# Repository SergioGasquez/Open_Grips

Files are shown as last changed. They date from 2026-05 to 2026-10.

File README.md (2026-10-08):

Open Grips – Isolated Frictionless Ergonomic Grip Training for FDP and FDS

## Original Project

The original project uses FreeCad for parametric modeling, and 3D printing for manufacturing. See PDF for full description

## Fitting Prometheus to your hand

See [`prometheus-fit/`](prometheus-fit/README.md): measure your hand from a photo and generate fitted,
print-ready STLs from the original parametric FreeCAD model.

## OpenSCAD models

[`openscad/`](openscad/README.md) rebuilds the Prometheus v43 and Sisyphus v27 STEP files, without the TPU
guard, as parametric OpenSCAD models that export every part for either hand.

## This Fork

The key things I was aiming to improve in this fork were:

### Standard file format

The FreeCAD file format exports were not easy to move between programs for modification. My hope is that by providing a .step file users in the future will be able to open and modify the file to their liking in whatever CAD software they use.

### Ease of printing

The original models were not set up for efficient FDM printing. Through the addition of new angled walls and the adjustment of other areas, the prints are now all sufficiently set up for FDM printing with no supports needed.

- The Sisyphus model has been completely redesigned to take on the style of the Prometheus model in terms of assembly and style, allowing simpler printing *and* assembly
- The pins may now be printed
- The pins may be printed horizontally for strength and reduced failures
- The long, structural pin may also be printed horizontally for strength and reduced failures
- The frame pieces may now be printed sideways, without supports
- The chamfers and fillets on both tools have been generally improved for FDM printing

### Additional guard top piece

I've added a top piece to be printed in TPU as a guard for the tools.

### Documentation

You're reading it! There's more work to be done, but the process of modifying the print files still needs some work.

### Simple file modification for each user

One of the core ideas advertised by a company out there is that each user's hand is a little different and requires minute adjustments to get things just right for each person. In practice, we've found this to be not majorly important (exact measurements and adjustments from person to person do not heavily impact the effectiveness of the training), but for major differences in hand/finger sizes it is definitely still relevant.

In the original models, this modification was done using parametric model variables. I wasn't very familiar with FreeCAD, so in moving over to Fusion360 I dropped the compatibility with these variables. I plan to work on reimplementing them as I'm able. (Unless someone else wants to? :) For now, modification will need to be done by hand.

Until I finish some new tooling for adjusting these files, I'll explain the gist of what we've thought through here:

#### Prometheus

##### Roller Up/Down Offset

The length of the full finger may be used for up/down placement offsets of the rollers. Using the pinky length as "0", you can then calculate the height of the offset of each roller by subtracting the height of the pinky from height of the finger.

So, if your pinky was 60mm:

(Vertical offset of 79mm Ring finger roller pin) = 79mm - 60mm = ~19mm

Vertical offset example

##### Roller Forward/Backward Offset

The length of the PIP joint to the DIP joint ("P->D") may be used for forward/backward offsets of the rollers. Using the pinky length as "0", you can then calculate the offset of each roller by subtracting the length of the pinky P->D from the finger P->D.

So, if your pinky P->D was 18.5mm:

(Horizontal offset of a 27mm Ring finger roller pin) = 27mm - 18.5mm = ~8.5mm

Horizontal offset example

##### Roof Height

The length of the DIP joint to the tip of your finger may be used to calculate the height of the roof of each finger roller to achieve an "ideal" angle to maintain.

(Roof Height) = (DIP to Fingertip) / tan(Desired Angle)

Based on our findings, the desired angles are roughly:

Index: 57°
Middle: 60°
Ring: 60°
Pinky: 55°

So, if your Index finger DIP to Fingertip was 28mm:
(Roof Height) = 28 / tan(57) = ~18.18mm

Roof height example

#### Sisyphus

##### Roller Offset

See each "Roller Offset" area above. Apply the same concepts.

##### Roller Diameter

TBD

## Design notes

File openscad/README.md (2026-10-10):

# OpenSCAD models

Parametric OpenSCAD rebuilds of the fork's printable designs: `prometheus.scad` rebuilds
`../OpenGrips Prometheus v43.step` and `sisyphus.scad` rebuilds `../OpenGrips Sisyphus v27.step`.
Every part (frame, walls, end wall, rollers, pins and post) exports print-ready, for the left or
the right hand, and all of them print in the same material: no metal rods, screws or TPU. The
only extra is the cord through the anchor. Both reproduce their STEP file at the STEP's values
(Prometheus defaults to one measured hand instead, see below), except the STEP files' TPU guard,
which is left out: nothing attaches to it, and the anchor's cord exits are rounded without it.

Requires OpenSCAD 2025 or newer (the Manifold backend; older releases take minutes per part).

## Open in OpenSCAD

Open `prometheus.scad` or `sisyphus.scad`, set the values in the Customizer (Window → Customizer),
pick a `part` and `hand`, render (F6) and export the STL. `part = "assembly"` shows all parts
in place; rendering it takes about a minute.

## Export all parts

```sh
python3 export.py prometheus ../prometheus-fit/examples/right-hand/params.txt --hand right --out my-right-hand
python3 export.py sisyphus --hand left --out sisyphus-left
```

The parameter file is optional and uses the format `../prometheus-fit/measure-hand.html` writes
(`Name = value` lines, `#` comments). The STLs are named like the FreeCAD generator's
(`prometheus_right_frame.stl`, …), so give them their own folder with `--out`.

## Parameters

### Prometheus

Names and meanings match the VarSet of `../Original/OpenGrips_Prometheus.FCStd`; see
`../prometheus-fit/README.md` for how to measure them. The finger defaults (`Height`, `Depth`,
`To_Blocker`) are one measured right hand, recorded at the top of `prometheus.scad` with the v43
values for comparison; the roller and frame sizes are the VarSet's. The frame length follows the middle finger, so its
`Base_M_Height + Base_M_To_Blocker` must be the largest; the model stops with a message if not.
Unlike the FreeCAD model, the ring and middle rails may overlap.

The outer faces of the frame and the end wall carry an engraved `crimpdeq.com` in Inter Bold, as on
the Crimpdeq case; the font is bundled in `fonts/` (SIL Open Font License). The model stops with a
message if the text does not fit between the end wall's post hole and lock.

### Sisyphus

The values of `../Original/OpenGrips_Sisyphus.FCStd`'s VarSet, renamed consistently
(`Base_<F>_height` → `Base_<F>_Height`, `Base_R_diamter` → `Base_R_Diameter`, `I_width` →
`Base_I_Width`, `Base_wall_width` → `Wall_Width`):

| Parameter | Meaning |
|---|---|
| `Base_<F>_Height` | Roller position along the fingers, relative to the pinky |
| `Base_<F>_Blocker` | How far the seat under each roller reaches past its axis (the pinky's stops short of it) |
| `Base_<F>_Diameter`, `Base_<F>_Width` | Roller size; all roller tops are level with the middle roller's |
| `Base_Frame_Height` | Wall length up to the lock slot |

The finger stops and the anchor have no counterpart in the original model and
keep v27's dimensions.

## Printing

The parts export in the orientation `../prometheus-fit/generate.py` uses: frame, walls and
rollers on their pinky-side face with the pole holes vertical, pins on their flat, the post on its
chamfered side. For Prometheus print settings see
`../prometheus-fit/README.md`.

## How faithful

`check_step.py` exports each part at the STEP's own values and compares it with the STEP solid
(run from the repository root; it tessellates the STEP files with FreeCAD's bundled Python):

```sh
uvx --with trimesh --with manifold3d --with scipy --with rtree python openscad/check_step.py
```

Every part is within 0.5% of the STEP volume and within 0.1 mm of its surface at the 95th
percentile, except the Prometheus end wall (0.26 mm) because of its engraving. Known differences:

- Prometheus blocker tips follow the original rule: v43's hand-moved tips sit 0.15–0.38 mm lower.
- Pins are centered in their holes; v43's index pin and v27's ring and index pins are 0.1 mm off.
- Sisyphus: the pinky cradle is approximated by one roller cut.
- Some exports contain a few zero-area triangles where rounded surfaces meet flat ones; slicers
  ignore them.

The comparison is geometric only; fit, strength and comfort still need a test print.

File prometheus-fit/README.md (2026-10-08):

# Fitting Prometheus to your hand

The original FreeCAD model (`../Original/OpenGrips_Prometheus.FCStd`) is still parametric. Two tools drive
it from a photo of your hand and export print-ready STLs. Only Prometheus is covered; Sisyphus is unchanged.

## 1. Measure

Open `measure-hand.html` in Chrome or Safari (single file, nothing to install).

- Photo: palm up, fingers straight and slightly apart, a millimetre ruler beside the fingers raised to
  palm height (e.g. on a book), phone parallel to the table and above the fingers. Use the original
  full-resolution JPEG or PNG, not a screenshot.
- Enter the distance between two ruler marks far apart (e.g. 0 and 10 cm = 100 mm) and click them.
- For each finger, from index to pinky, click the base crease, middle joint (PIP) crease, end joint
  (DIP) crease and fingertip. Scroll to zoom, drag to pan or move a point.
- Copy the text block into `params.txt` in a new folder, e.g. `examples/my-right-hand/params.txt`.

The page sets three values per finger, relative to the pinky:

| Value | Meaning | Computed from |
|---|---|---|
| `Height` | Roller up/down | Fingertip position in the claw grip from `../Original/Open_Grips.pdf` (proximal phalanx vertical, PIP and DIP flexed 55°), including how far each base crease sits along the hand |
| `Depth` | Roller forward/backward | Same claw grip, front-to-back fingertip position |
| `To_Blocker` | Roof height | `DIP→tip / tan(angle)`, with the angles from the [main README](../README.md#roof-height) |

`Height` deliberately differs from the "full finger length minus pinky length" rule in the
[main README](../README.md#roller-updown-offset): that rule ignores that the pinky starts lower on the
hand, which put the rollers 8–14 mm too low on the example hand.

## 2. Generate

With FreeCAD 1.1 installed, from this folder:

```sh
/Applications/FreeCAD.app/Contents/Resources/bin/python generate.py examples/right-hand/params.txt --hand right
```

This writes one STL per part next to `params.txt`, already oriented for printing. The original model is a
left-hand grip; `--hand right` mirrors it. The metal rods of the original are replaced by printed pins
sized like the fork's v43 pins. Parts: frame, ring/middle/index walls, end wall, four rollers, four pins
and the post.

If the ring and middle rollers end up too close, the generator stops and says how much to raise
`Base_M_Height` or lower `Base_R_Height`; split the difference between the two.

The same `params.txt` also drives the OpenSCAD rebuild of the fork's v43 design, without FreeCAD and
without the rail limit: see [`../openscad/`](../openscad/README.md).

`examples/right-hand/` is one person's right hand, as an example.

## 3. Print

All parts in PETG (HF), 0.2 mm layers, 5 walls, 35% cubic infill, textured PEI plate. Enable supports
only for the frame (add a 5 mm brim, it stands 111 mm tall) and the index wall. Pins print lying on
their flat side. `examples/right-hand/prometheus_right_A1.3mf` is a Bambu Lab A1 project with these
settings; rebuild it whenever the STLs change (see `../AGENTS.md`).

Assemble as in `../Original/Open_Grips.pdf` section 3.2: place a roller, insert its pin, slide the next
wall onto the rails, repeat, add the end wall and push the post through the side hole.

The fit has only been checked digitally; adjust the values after a test print.

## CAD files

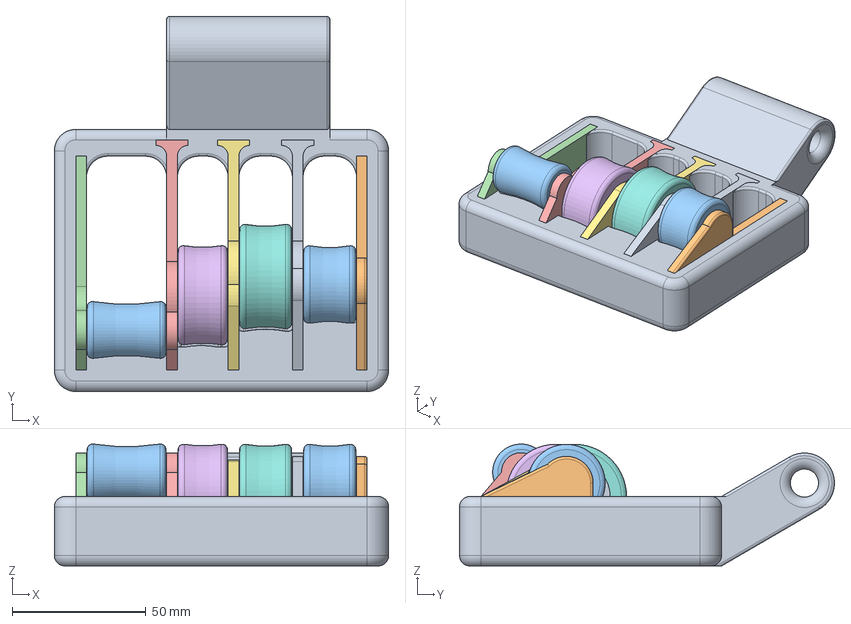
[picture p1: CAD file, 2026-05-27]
docs/templates/OpenGrips_Sisyphus.FCStd
125.0 x 140.2 x 45.6 mm
frame
P_Pole
P_Roller_print
Wall_1_print
Wall_2_print
R_Roller_print
Wall_3_print
M_Roller_print
Wall_4_print
Wall_5_print
I_Roller_print

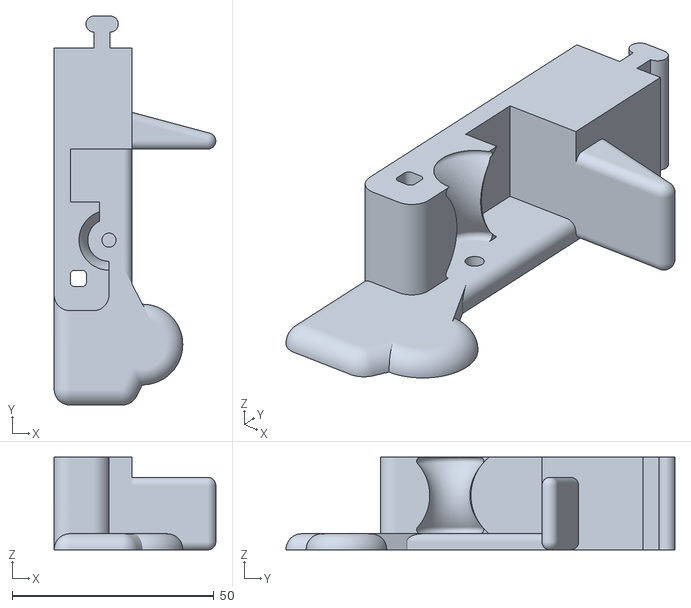
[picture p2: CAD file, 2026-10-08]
prometheus-fit/examples/right-hand/prometheus_right_ring_wall.stl
40.1 x 96.5 x 23.0

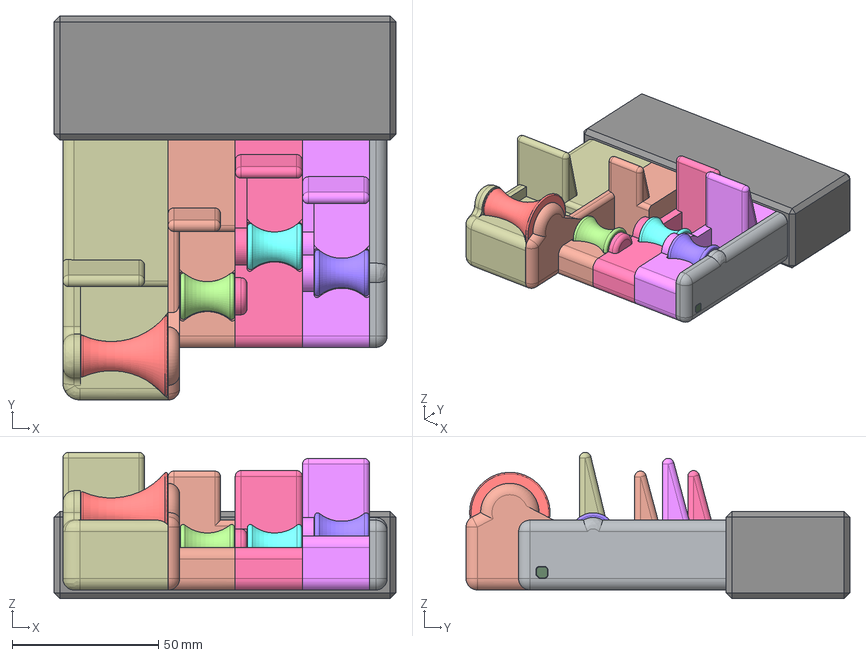
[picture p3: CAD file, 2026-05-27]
prometheus.step
117.0 x 131.4 x 50.1 mm
Frame
Pinky Roller
Pinky Pin
Ring Wall
Ring Roller
Ring Pin
Middle Wall
Middle Roller
Middle Pin
Index Wall
Index Roller
Index Pin
End Wall
Post
Guard

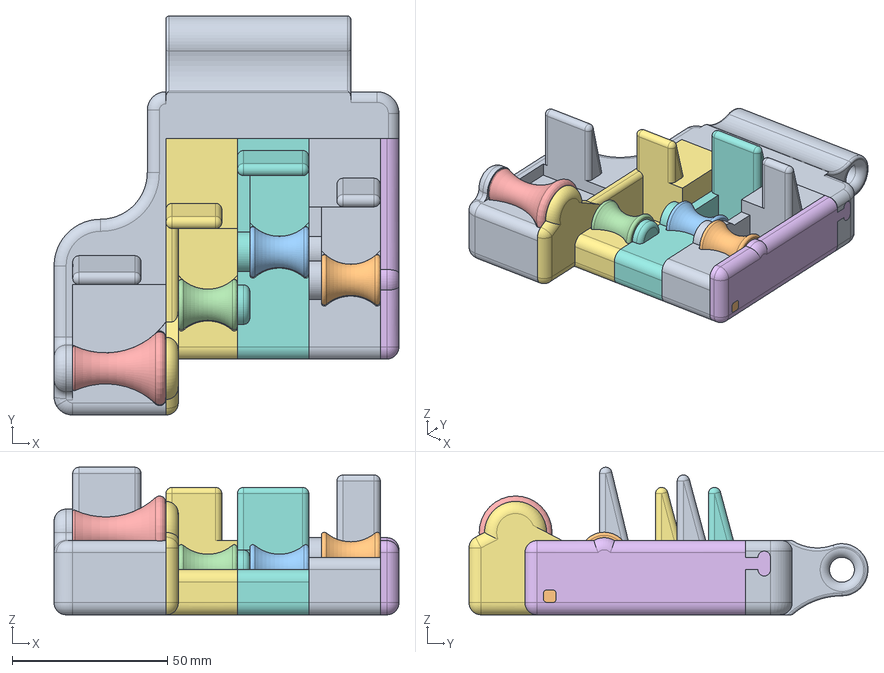
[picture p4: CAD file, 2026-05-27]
docs/templates/OpenGrips_Prometheus.FCStd
111.0 x 128.4 x 47.5 mm
Frame
I_Roller
M_Roller
R_Roller
P_Roller
End_Wall_5
Cut_R_wall
Cut_M_wall
Cut_I_wall
Post

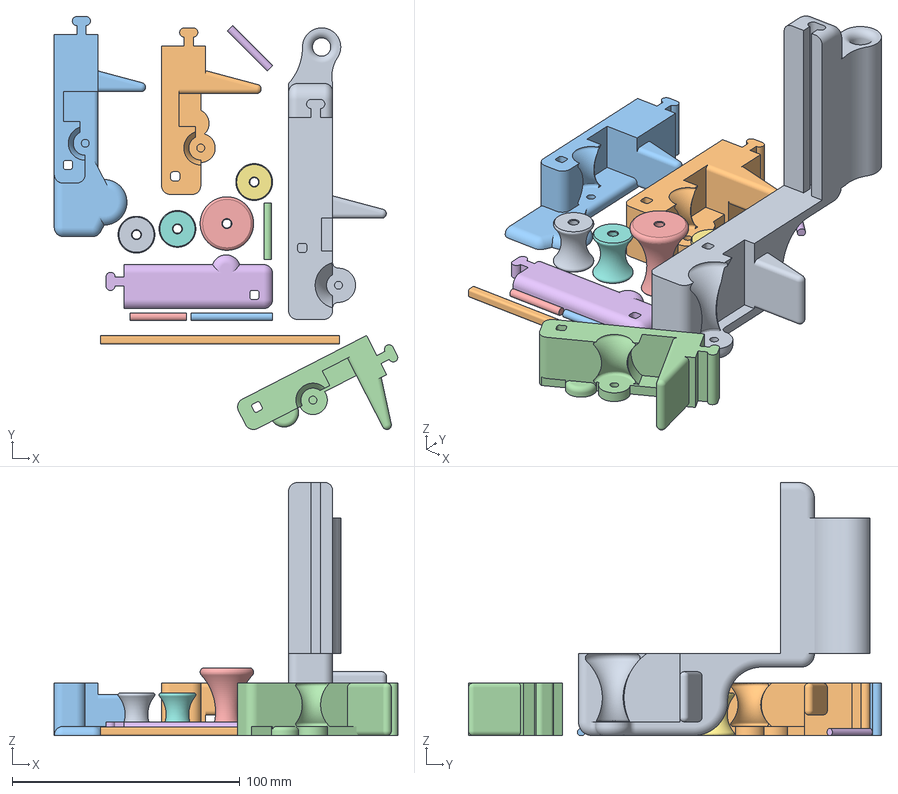
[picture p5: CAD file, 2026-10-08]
prometheus-fit/examples/right-hand/prometheus_right_A1.3mf
150.7 x 181.2 x 111.0 mm
prometheus_right_frame.stl
prometheus_right_index_wall.stl
prometheus_right_ring_wall.stl
prometheus_right_middle_wall.stl
prometheus_right_pinky_roller.stl
prometheus_right_end_wall.stl
prometheus_right_index_roller.stl
prometheus_right_ring_roller.stl
prometheus_right_middle_roller.stl
prometheus_right_post.stl
prometheus_right_pinky_pin.stl
prometheus_right_middle_pin.stl
prometheus_right_index_pin.stl
prometheus_right_ring_pin.stl

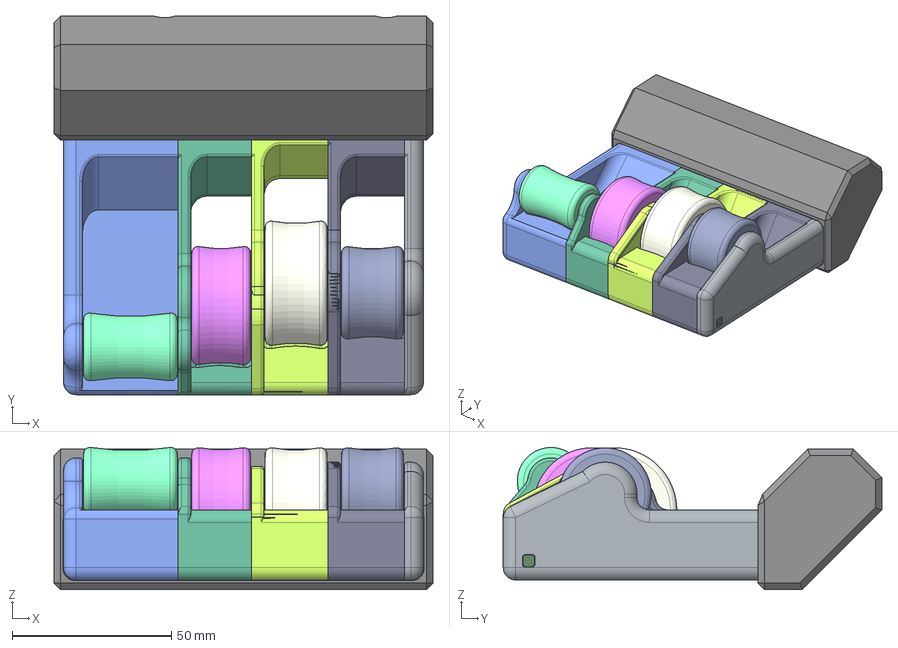
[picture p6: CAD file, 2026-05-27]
sisyphus.step
119.0 x 118.8 x 44.6 mm
Frame
Pinky Roller
Pinky Pin
Ring Wall
Ring Roller
Ring Pin
Middle Wall
Middle Roller
Middle Pin
Index Wall
Index Roller
Index Pin
End Wall
Post
Guard

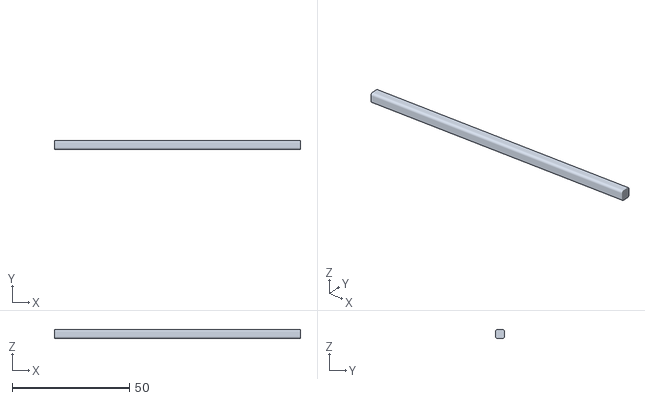
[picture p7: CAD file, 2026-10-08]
prometheus-fit/examples/right-hand/prometheus_right_post.stl
104.8 x 3.80 x 3.80

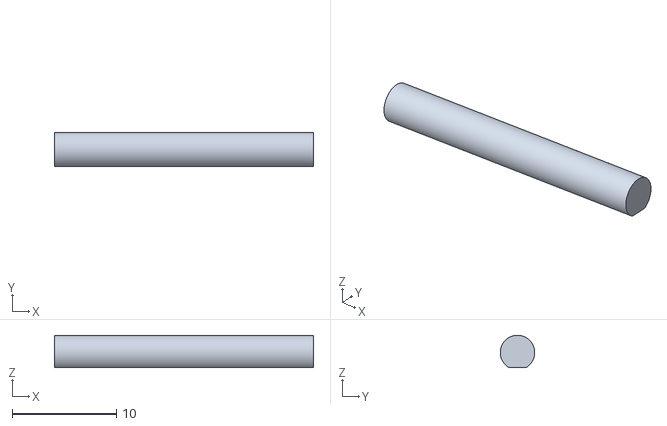
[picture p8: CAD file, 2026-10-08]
prometheus-fit/examples/right-hand/prometheus_right_middle_pin.stl
24.8 x 3.30 x 3.10

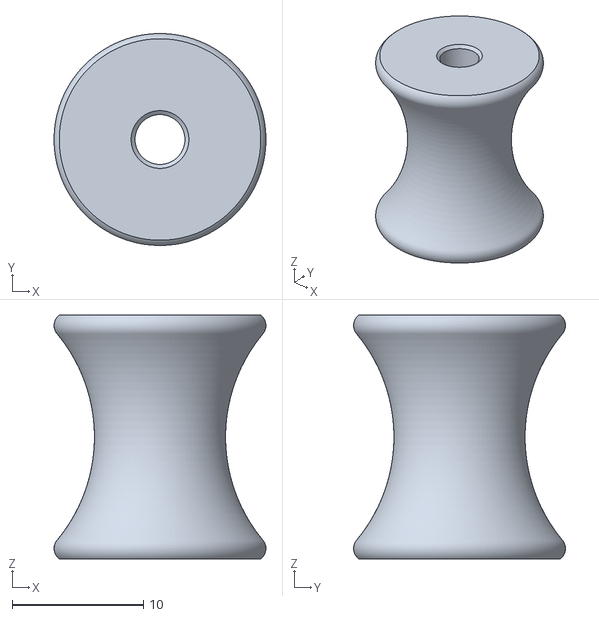
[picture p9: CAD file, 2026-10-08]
prometheus-fit/examples/right-hand/prometheus_right_ring_roller.stl
16.2 x 16.2 x 18.6

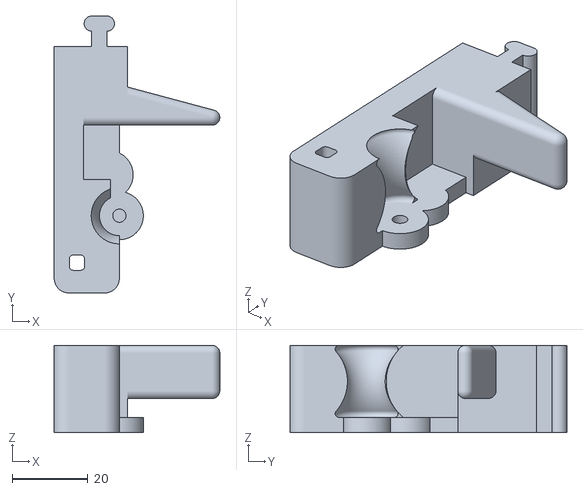
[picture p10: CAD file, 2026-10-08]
prometheus-fit/examples/right-hand/prometheus_right_index_wall.stl
43.7 x 73.1 x 23.0

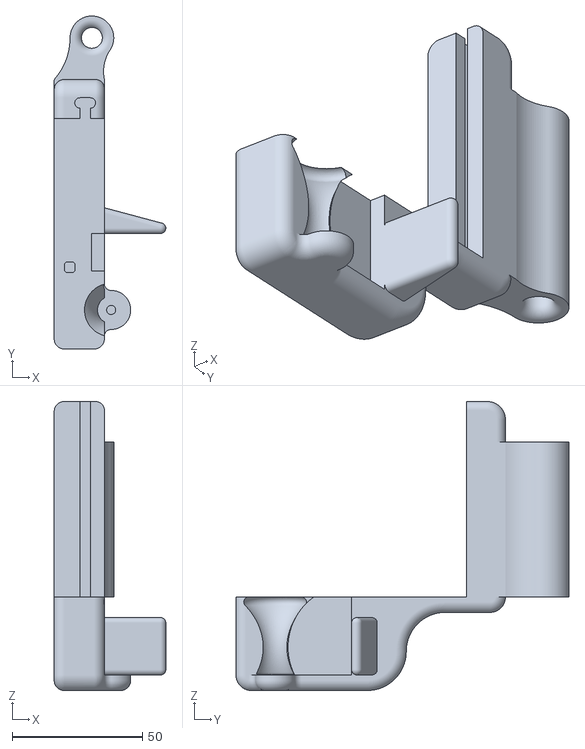
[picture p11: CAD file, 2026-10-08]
prometheus-fit/examples/right-hand/prometheus_right_frame.stl
42.9 x 127.9 x 111.0

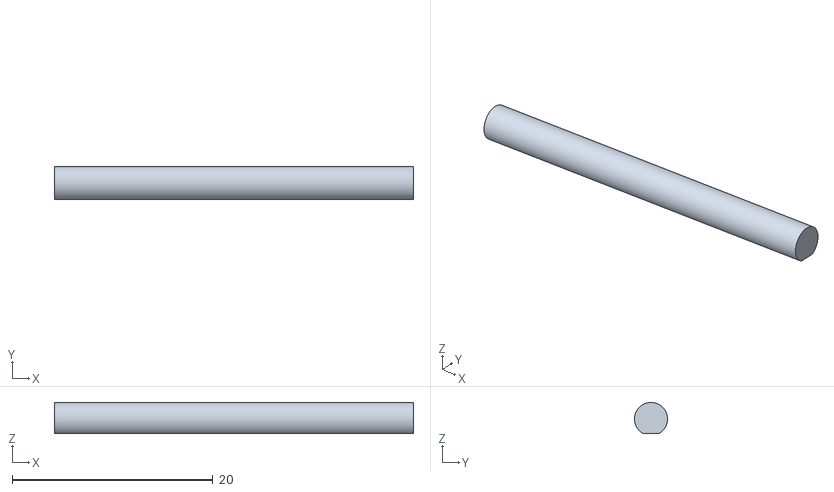
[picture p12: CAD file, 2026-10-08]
prometheus-fit/examples/right-hand/prometheus_right_pinky_pin.stl
35.8 x 3.30 x 3.10

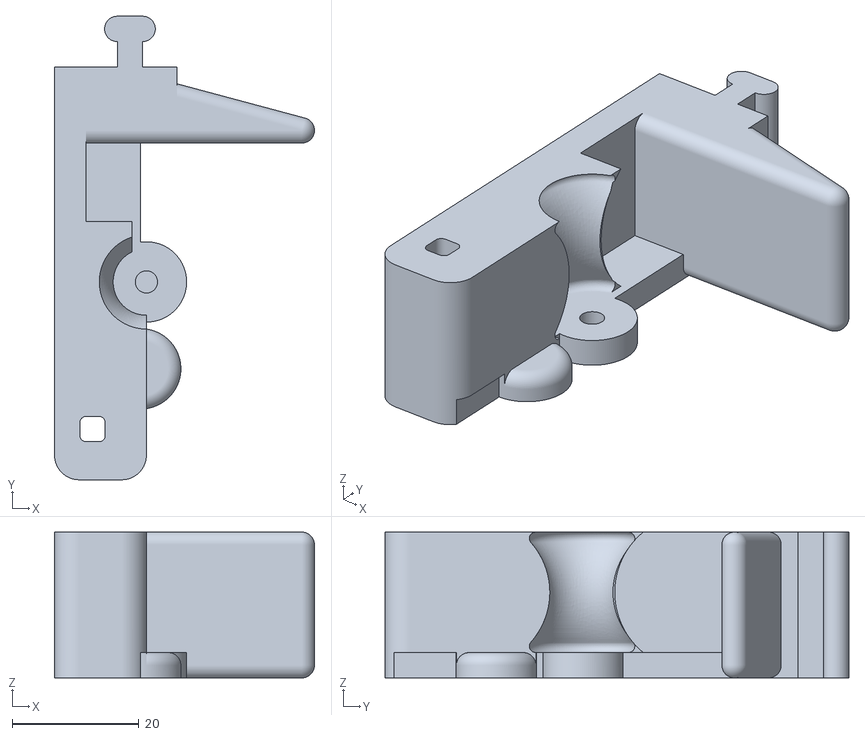
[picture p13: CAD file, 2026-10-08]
prometheus-fit/examples/right-hand/prometheus_right_middle_wall.stl
41.0 x 73.1 x 23.0

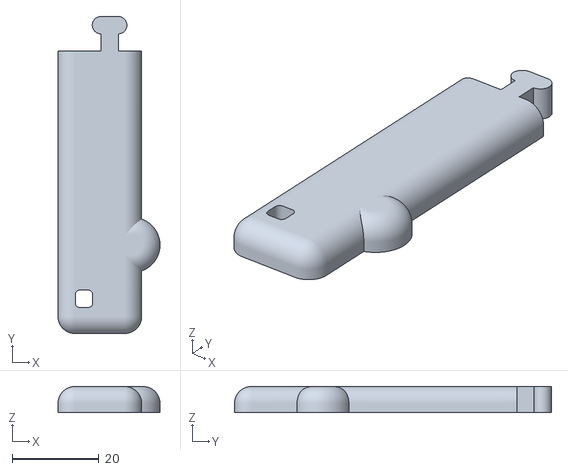
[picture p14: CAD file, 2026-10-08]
prometheus-fit/examples/right-hand/prometheus_right_end_wall.stl
23.5 x 73.1 x 6.00

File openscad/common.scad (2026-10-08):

// Shared building blocks of the OpenGrips models (use <common.scad>).
//
// Model coordinates: X runs across the fingers along the roller axes, Y along the fingers, Z is
// depth; 2D profiles are drawn in (Y, Z) and extruded along X unless noted.

eps = 0.01;

// Extrude a 2D (Y, Z) profile along X.
module along_x(x0, x1) {
  translate([x0, 0, 0]) rotate([90, 0, 90]) linear_extrude(x1 - x0) children();
}

// Extrude a 2D (X, Z) profile along Y.
module along_y(y0, y1) {
  translate([0, y1, 0]) rotate([90, 0, 0]) linear_extrude(y1 - y0) children();
}

// Revolve a 2D (along the axis, radius) profile about the X axis through [x0, y, z].
module about_x_axis(x0, y, z) {
  translate([x0, y, z]) rotate([0, 90, 0]) rotate([0, 0, 90])
    rotate_extrude() rotate([0, 0, 90]) mirror([0, 1, 0]) children();
}

// Round convex corners (r > 0) or concave corners (r < 0) of a 2D shape. Round joins on both
// steps: delta (mitred) joins spike through the shape at tangent cusps.
module round2d(r) {
  offset(r) offset(-r) children();
}

// children() with the convex corners inside the window [p0, p1] rounded by r.
module round_corners_in(r, p0, p1) {
  difference() { children(); translate(p0) square(p1 - p0); }
  intersection() { round2d(r) children(); translate(p0) square(p1 - p0); }
}

// Rectangle from p0 to p1 with its two low-X corners rounded by r.
module front_rounded2d(p0, p1, r) {
  intersection() {
    round2d(r) translate(p0) square([p1[0] - p0[0] + r, p1[1] - p0[1]]);
    translate(p0) square(p1 - p0);
  }
}

// Sphere for rounding: polyhedral spheres fall short of r along the axes, so scale up the facets.
module ball(r) {
  scale(1 / cos(180 / 48)) sphere(r, $fn = 48);
}

// Extrude a (Y, Z) profile along X with the perimeter edges of one end face rounded by r
// (side = 1: the face at x1, side = -1: at x0). children(1), if given, is a larger profile
// whose extra area keeps the edges it covers sharp; it must reach r past those edges.
// The rounded end is the eroded profile, t thick, swept by a ball; the sharp part ends inside
// that core so the two share no faces.
module along_x_rounded(x0, x1, r, side) {
  face = side > 0 ? x1 : x0;
  t = 0.5;
  intersection() {
    along_x(x0, x1) children(0);
    union() {
      if (side > 0) along_x(x0 - 1, x1 - r - t / 2) children($children - 1);
      else along_x(x0 + r + t / 2, x1 + 1) children($children - 1);
      minkowski() {
        along_x(min(face - side * r, face - side * (r + t)), max(face - side * r, face - side * (r + t)))
          offset(-r) children($children - 1);
        ball(r);
      }
    }
  }
}

// Material to remove to round by r the edge along `axis` ("x" or "y") through point `at`, where
// the solid lies toward -sign in the two other axes (sign = [s1, s2]).
module edge_round_cutter(axis, from, to, at, r, sign) {
  module cutter2d() {
    translate(at) scale(sign) difference() {
      translate([-r, -r]) square(r + eps);
      translate([-r, -r]) circle(r);
    }
  }
  if (axis == "x") along_x(from, to) cutter2d();
  else along_y(from, to) cutter2d();
}

function arc_points(c, r, a0, a1, n = 24) =
  [for (k = [0:n]) c + r * [cos(a0 + (a1 - a0) * k / n), sin(a0 + (a1 - a0) * k / n)]];

// Intersection of the circles (c0, r0) and (c1, r1) on the left of the line from c0 to c1.
function circle_intersection(c0, r0, c1, r1) =
  let(d = norm(c1 - c0), u = (c1 - c0) / d, a = (r0 * r0 - r1 * r1 + d * d) / (2 * d))
  c0 + a * u + sqrt(r0 * r0 - a * a) * [-u[1], u[0]];

// Printed pin along X over [x0, x1] at (y, z): a cylinder with a flat on its underside so it
// prints lying down.
module pin(x0, x1, y, z, d, flat) {
  r = d / 2;
  translate([x0, y, z]) difference() {
    rotate([0, 90, 0]) cylinder(r = r, h = x1 - x0);
    translate([-1, -r, -r - 1]) cube([x1 - x0 + 2, 2 * r, 1 + flat]);
  }
}

// Post cross-section (Y, Z) from p (its low corner): a rounded square whose low corner is
// chamfered, which keys the post in its holes.
module post2d(p, size) {
  translate(p) hull() {
    for (q = [[1, size - 1], [size - 1, size - 1], [size - 1, 1]]) translate(q) circle(1);
    polygon([[0, 1], [1, 0], [1, 1]]);
    translate([0, 1]) square([eps, size - 2]);
    translate([1, 0]) square([size - 2, eps]);
  }
}

// Lock tongue / slot cross-section (Y, Z): a bar of thickness w from y0, 2w long, with round
// beads of diameter w at its end that hook the walls into the frame.
module lock2d(y0, z0, w) {
  translate([y0 - eps, z0]) square([2 * w + eps, w]);
  for (z = [z0, z0 + w]) translate([y0 + 1.5 * w, z]) circle(w / 2);
}

// Material removed to round by r the edge where a bore along X (center [y, z], radius rb)
// breaks out of the vertical end plane through p0 (in plan) with outward unit normal n. A ball
// rolls along the edge touching the bore and the plane; between the edge and its path lies the
// cut.
module bore_exit_round(center, rb, p0, n, r) {
  steps = 72;
  d = 0.05; // overshoot into the air so the cut leaves no slivers
  // x where the plane passes through bore radius rho at angle t, offset off along n.
  function x_on_plane(rho, t, off) =
    let(y = center[0] + rho * cos(t)) (n * p0 + off - n[1] * y) / n[0];
  function ring(rho, t) = center + rho * [cos(t), sin(t)];
  function corner(t) = let(
    e = concat([x_on_plane(rb, t, 0)], ring(rb, t)),
    c = concat([x_on_plane(rb + r, t, -r)], ring(rb + r, t)),
    f1 = concat([c[0]], ring(rb - d, t)),
    f2 = c + (r + d) * [n[0], n[1], 0],
    out = (e - c) / norm(e - c))
    [e + d * out, f1, f2, c];
  // Neighbouring pieces overlap slightly so they share no faces.
  for (k = [0:steps - 1]) {
    a = corner(360 * (k - 0.1) / steps);
    b = corner(360 * (k + 1.1) / steps);
    // The ball is a touch larger so its path crosses the bore and plane instead of touching
    // them, which booleans cannot resolve cleanly.
    difference() {
      hull() for (q = [a[0], a[1], a[2], b[0], b[1], b[2]]) translate(q) cube(0.01, center = true);
      hull() for (q = [a[3], b[3]]) translate(q) ball(r + 0.02);
    }
  }
}

// Mirror for a right-hand grip; the models are left-hand grips.
module hand_mirror(hand) {
  assert(hand == "left" || hand == "right", str("hand must be left or right, got ", hand));
  if (hand == "right") mirror([1, 0, 0]) children();
  else children();
}

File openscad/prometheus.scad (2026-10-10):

// OpenGrips Prometheus: parametric rebuild of the fork's "OpenGrips Prometheus v43.step".
//
// Coordinates follow the original FreeCAD model, a left-hand grip: X runs across the fingers
// along the roller axes (pinky at low X), Y along the fingers, Z is depth (frame bottom at 0).
// Parameter names and meanings match the VarSet of ../Original/OpenGrips_Prometheus.FCStd, so the
// output of ../prometheus-fit/measure-hand.html applies unchanged.

use <common.scad>
use <fonts/Inter-Bold.ttf>

/* [Output] */
part = "assembly"; // [assembly, frame, pinky_roller, ring_roller, middle_roller, index_roller, ring_wall, middle_wall, index_wall, end_wall, pinky_pin, ring_pin, middle_pin, index_pin, post]
// The model is a left-hand grip; right mirrors every part.
hand = "left"; // [left, right]

/* [Fingers, relative to the pinky (mm)] */
// Defaults: one measured right hand, measure-hand.html on PXL_20261008_143506195.jpg (ruler 100 mm,
// 12.6 px/mm). v43 itself: Height 23/32/15/0, Depth 8/12/12/0, To_Blocker 14.2/13.9/12.7/8.8
// (index/middle/ring/pinky) and Base_Frame_Height 104.
// Roller up/down (fingertip position along the fingers)
Base_I_Height = 23.5;
Base_M_Height = 32.1;
Base_R_Height = 22.0;
Base_P_Height = 0;
// Roller forward/backward
Base_I_Depth = 4.2;
Base_M_Depth = 6.7;
Base_R_Depth = 8.4;
Base_P_Depth = 0;
// Roof height: roller top to blocker
Base_I_To_Blocker = 13.8;
Base_M_To_Blocker = 12.0;
Base_R_To_Blocker = 13.2;
Base_P_To_Blocker = 13.9;

/* [Rollers (mm)] */
Base_I_Diameter = 19;
Base_M_Diameter = 19;
Base_R_Diameter = 19;
Base_P_Diameter = 30;
Base_I_Width = 19;
Base_M_Width = 19;
Base_R_Width = 19;
Base_P_Width = 30;

/* [Frame (mm)] */
Wall_Width = 4;
Base_Ext_Wall_Width = 6;
Base_Blocker_Height = 30;
// The original metal pole; still sets the frame thickness and rail details.
Base_Pole_Diameter = 2.6;

/* [Printed pins (mm)] */
pin_diameter = 3.3;
pin_flat = 0.2; // flat along the pin so it prints lying down
pin_end_clearance = 0.1; // to each blind hole bottom
pin_hole_diameter = 3.5;
roller_bore_diameter = 3.8;
roller_bore_chamfer = 0.5;
roller_side_clearance = 0.2; // to each wall
post_clearance = 0.15; // per side

/* [Hidden] */
in_place = false; // export a part in assembly coordinates (checks against the STEP)
$fa = 3;
$fs = 0.3;
eps = 0.01;

// Fingers in X order from the pinky side.
P = 0; R = 1; M = 2; I = 3;
FINGERS = ["pinky", "ring", "middle", "index"];
HEIGHT = [Base_P_Height, Base_R_Height, Base_M_Height, Base_I_Height];
DEPTH = [Base_P_Depth, Base_R_Depth, Base_M_Depth, Base_I_Depth];
TO_BLOCKER = [Base_P_To_Blocker, Base_R_To_Blocker, Base_M_To_Blocker, Base_I_To_Blocker];
DIAMETER = [Base_P_Diameter, Base_R_Diameter, Base_M_Diameter, Base_I_Diameter];
WIDTH = [Base_P_Width, Base_R_Width, Base_M_Width, Base_I_Width];

E = Base_Ext_Wall_Width;
W = Wall_Width;
POLE = Base_Pole_Diameter;
Base_Frame_Depth = Base_M_Depth + Base_M_Diameter / 2 + 5;
Base_Frame_Height = 2 * E + Base_P_Diameter + Base_M_Height + Base_M_To_Blocker + 15;
Base_Frame_Width = 3 * W + WIDTH[P] + WIDTH[R] + WIDTH[M] + WIDTH[I] + 2 * E;
FD = Base_Frame_Depth;
FW = Base_Frame_Width;
T = FD - POLE; // thickness (Z) of the frame plate and the walls
FRAME_TOP = E + Base_Frame_Height; // Y where the anchor starts

ROLLER_WAIST = 5; // smallest roller radius
POLE_HOLE_DEPTH = 3;
EDGE_R = 3.9; // outer edge rounds (Wall_Width - 0.1 in the FreeCAD model)
BLOCKER_R = 2; // blocker tip and edge rounds
FLOOR_ABOVE_ROLLER = 1; // the floor in front of each roller sits this far above its bottom
CRADLE_SCALE = 1.05; // radial clearance of the cradle under each roller

// Rollers, walls and blockers (Y, Z in assembly coordinates).
function sum(v, n) = n <= 0 ? 0 : v[n - 1] + sum(v, n - 1);
function roller_x(f) = E + sum(WIDTH, f) + f * W;
function wall_x(f) = roller_x(f) - W; // the wall plate on the pinky side of roller f
END_WALL_X = roller_x(I) + WIDTH[I];
function axis_y(f) = E + DIAMETER[P] + HEIGHT[f] - DIAMETER[f] / 2;
function axis_z(f) = FD - DEPTH[f];
function axis(f) = [axis_y(f), axis_z(f)];
function blocker_y(f) = E + DIAMETER[P] + HEIGHT[f] + TO_BLOCKER[f];
// Roller end radii: the pinky roller is a cone-like spool, the others are symmetric.
function roller_end_radii(f) = f == P ? [DIAMETER[P] / 4, DIAMETER[P] / 2] : [DIAMETER[f] / 2, DIAMETER[f] / 2];

// Concave roller profile: a circle through both end radii with ROLLER_WAIST as its lowest point.
// Returns [center along the roller, radius] for a roller of width w.
function roller_arc(w, r0, r1) =
  let(a = r0 - ROLLER_WAIST, b = r1 - ROLLER_WAIST)
  a == b ? [w / 2, (w * w / 4 + a * a) / (2 * a)]
  : let(A = 1 - b / a, c = (2 * w - sqrt(4 * w * w - 4 * A * (w * w + b * b - a * b))) / (2 * A))
    [c, (c * c + a * a) / (2 * a)];

WALL_Y0 = E + DIAMETER[P] + HEIGHT[R] - DIAMETER[R] - 2 * W; // front of the ring, middle, index and end walls
LOCK_Y = Base_Frame_Height - E - 15 + 3 * W; // crossbar front, lock slot start
LOCK_Z = FD - 3 * W;
POST_Y = WALL_Y0 + E;
POST_Z = W;
POST_SIZE = 4;

// Anchor: tube along X behind the crossbar that a cord pulls on.
ANCHOR_Y = FRAME_TOP + 16;
ANCHOR_Z = FD - Base_M_Depth;
ANCHOR_BORE_R = 4;
ANCHOR_R = ANCHOR_BORE_R + 4.4;
ANCHOR_X0 = E + WIDTH[P]; // its 45 degree ends pass through these X at the tube top
ANCHOR_X1 = roller_x(I) + WIDTH[I] / 2;
CORD_EXIT_R = 3; // round of the bore where it breaks out of the anchor ends

// Engraved on the outer faces of the frame and the end wall, as on the back of the Crimpdeq case.
// Centered between the end wall's post hole and lock, at the same Y on the frame.
BRAND_TEXT = "crimpdeq.com";
BRAND_FONT = "Inter:style=Bold";
BRAND_SIZE = 4.5;
BRAND_DEPTH = 0.8;
BRAND_Y = (POST_Y + POST_SIZE + LOCK_Y) / 2;
BRAND_EXTENT = textmetrics(BRAND_TEXT, size = BRAND_SIZE, font = BRAND_FONT).size; // [along Y, Z]

for (f = [P:I])
  assert(blocker_y(f) + 2 * BLOCKER_R < LOCK_Y,
         str(FINGERS[f], " blocker (Y ", blocker_y(f), ") reaches the crossbar (Y ", LOCK_Y,
             "): the middle finger must have the largest Height + To_Blocker"));
assert(BRAND_EXTENT[0] + 2 < LOCK_Y - POST_Y - POST_SIZE,
       str("the end wall (", LOCK_Y - POST_Y - POST_SIZE, " mm between post hole and lock) is too short for ",
           BRAND_TEXT));
assert(BRAND_Y - BRAND_EXTENT[0] / 2 > axis_y(P) + DIAMETER[P] / 4 + POLE,
       str(BRAND_TEXT, " reaches the pinky pole wall on the frame"));
assert(BRAND_EXTENT[1] + 1 < T - 2 * EDGE_R,
       str("the frame (", T, " mm thick) is too thin for ", BRAND_TEXT));

// ---------------------------------------------------------------------------------------------
// Rollers, pins, post

// Half profile (along the axis, radius) of roller f over [u0, u1], ends rounded by [rf0, rf1].
module roller_half_profile(f, u0, u1, rf) {
  w = WIDTH[f];
  arc = roller_arc(w, roller_end_radii(f)[0], roller_end_radii(f)[1]);
  rmax = max(roller_end_radii(f)) + 1;
  // Mirror across the axis so rounding leaves the axis side alone, then keep the upper half.
  intersection() {
    translate([u0 - 1, 0]) square([u1 - u0 + 2, rmax + 1]);
    union() {
      for (k = [0, 1]) intersection() {
        round2d(rf[k]) roller_body2d();
        translate([k == 0 ? u0 - 1 : (u0 + u1) / 2, -rmax - 1]) square([(u1 - u0) / 2 + 1, 2 * rmax + 2]);
      }
    }
  }
  module roller_body2d() {
    difference() {
      translate([u0, -rmax]) square([u1 - u0, 2 * rmax]);
      for (s = [1, -1]) translate([arc[0], s * (ROLLER_WAIST + arc[1])]) circle(arc[1]);
    }
  }
}

// Solid of revolution about the roller f axis from a (along the axis, radius) profile at local u.
module about_roller_axis(f) {
  about_x_axis(roller_x(f), axis_y(f), axis_z(f)) children();
}

// The printed roller: trimmed for side clearance, ends rounded, chamfered bore for the pin.
module roller(f) {
  w = WIDTH[f];
  rf = f == P ? 0.5 : 1;
  c = roller_side_clearance;
  difference() {
    about_roller_axis(f) roller_half_profile(f, c, w - c, [rf, rf]);
    about_roller_axis(f) polygon([
      [c - eps, 0], [c - eps, roller_bore_diameter / 2 + roller_bore_chamfer + eps],
      [c + roller_bore_chamfer, roller_bore_diameter / 2], [w - c - roller_bore_chamfer, roller_bore_diameter / 2],
      [w - c + eps, roller_bore_diameter / 2 + roller_bore_chamfer + eps], [w - c + eps, 0]]);
  }
}

// Space cut under roller f: the original roller (no side clearance, its own end rounds) with
// CRADLE_SCALE radial clearance, never wider than its largest end. It reaches eps past the
// walls on both sides so its ends never coincide with their faces.
module cradle(f) {
  w = WIDTH[f];
  rf = f == P ? [0.5, 0] : [1, 1];
  about_roller_axis(f) translate([w / 2, 0]) scale([(w + 2 * eps) / w, 1]) translate([-w / 2, 0]) intersection() {
    scale([1, CRADLE_SCALE]) roller_half_profile(f, 0, w, rf);
    square([w, max(roller_end_radii(f))]);
  }
}
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

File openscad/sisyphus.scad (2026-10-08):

// OpenGrips Sisyphus: parametric rebuild of the fork's "OpenGrips Sisyphus v27.step".
//
// Coordinates: a left-hand grip, X across the fingers along the roller axes (pinky at low X),
// Y along the fingers, Z depth; the frame's front bottom corner is the origin (the STEP is
// offset by [5.965, 8.069, 4.13]). Parameters follow the VarSet of
// ../Original/OpenGrips_Sisyphus.FCStd under consistent names (there: Base_<F>_height,
// Base_<F>_blocker, Base_<F>_diameter, Base_R_diamter, I_width, Base_wall_width).

use <common.scad>

/* [Output] */
part = "assembly"; // [assembly, frame, pinky_roller, ring_roller, middle_roller, index_roller, ring_wall, middle_wall, index_wall, end_wall, pinky_pin, ring_pin, middle_pin, index_pin, post]
// The model is a left-hand grip; right mirrors every part.
hand = "left"; // [left, right]

/* [Fingers, relative to the pinky (mm)] */
// Roller position along the fingers
Base_I_Height = 21;
Base_M_Height = 29;
Base_R_Height = 21;
Base_P_Height = 0;
// Seat under each roller: how far it reaches past the roller axis (pinky: short of it)
Base_I_Blocker = 4;
Base_M_Blocker = 9;
Base_R_Blocker = 10;
Base_P_Blocker = 1;

/* [Rollers (mm)] */
Base_I_Diameter = 30;
Base_M_Diameter = 40;
Base_R_Diameter = 38;
Base_P_Diameter = 22;
Base_I_Width = 20;
Base_M_Width = 20;
Base_R_Width = 19;
Base_P_Width = 30;

/* [Frame (mm)] */
Wall_Width = 4;
Base_Ext_Wall_Width = 6;
// Length of the walls up to the lock slot
Base_Frame_Height = 80;

/* [Printed pins (mm)] */
pin_diameter = 3.3;
pin_flat = 0.2; // flat along the pin so it prints lying down
pin_end_clearance = 0.1; // to each blind hole bottom
pin_hole_diameter = 3.5;
roller_bore_diameter = 3.8;
roller_side_clearance = 0.25; // to each wall
post_clearance = 0.15; // per side

/* [Hidden] */
in_place = false; // export a part in assembly coordinates (checks against the STEP)
$fa = 3;
$fs = 0.3;
eps = 0.01;

// Fingers in X order from the pinky side.
P = 0; R = 1; M = 2; I = 3;
FINGERS = ["pinky", "ring", "middle", "index"];
HEIGHT = [Base_P_Height, Base_R_Height, Base_M_Height, Base_I_Height];
BLOCKER = [Base_P_Blocker, Base_R_Blocker, Base_M_Blocker, Base_I_Blocker];
DIAMETER = [Base_P_Diameter, Base_R_Diameter, Base_M_Diameter, Base_I_Diameter];
WIDTH = [Base_P_Width, Base_R_Width, Base_M_Width, Base_I_Width];

E = Base_Ext_Wall_Width;
W = Wall_Width;
FW = 3 * W + WIDTH[P] + WIDTH[R] + WIDTH[M] + WIDTH[I] + 2 * E; // frame width
WH = Base_M_Diameter / 2 + W / 2; // wall and frame height (Z)

EDGE_R = 3.9; // outer edge rounds
TOP_EDGE_R = 1; // rounds along the wall plate tops
ROLLER_ARC_R = [80, 40, 40, 40]; // concave roller profile radius
ROLLER_END_R = 2;
CRADLE_SCALE = 1.05; // the cradles are cut by the original rollers scaled up by this
// v27 cuts each cradle with roller tools at these offsets from the roller slot (twice, leftovers
// of the original model; the pinky's single cut is fitted to v27).
CRADLE_TOOL_OFFSETS = [[-1], [0, -1.75], [0, -0.75], [0, 0.25]];

// Rollers (Y, Z in assembly coordinates). All roller tops are level with the middle roller's.
function sum(v, n) = n <= 0 ? 0 : v[n - 1] + sum(v, n - 1);
function roller_x(f) = E + sum(WIDTH, f) + f * W;
function wall_x(f) = roller_x(f) - W; // the wall plate on the pinky side of roller f
END_WALL_X = roller_x(I) + WIDTH[I];
function axis_y(f) = W + DIAMETER[P] + HEIGHT[f] - DIAMETER[f] / 2;
function axis_z(f) = W / 2 + Base_M_Diameter - DIAMETER[f] / 2;
function axis(f) = [axis_y(f), axis_z(f)];
function seat_end(f) = f == P ? axis_y(P) - BLOCKER[P] : axis_y(f) + BLOCKER[f];
function hump_r(f) = DIAMETER[f] / 3; // raised arc of the wall plates around each pole

LOCK_Y = Base_Frame_Height; // walls end and the lock slot starts
LOCK_Z = 10.37; // as in v27 (the Prometheus slot height, copied over)
POST_Y = E;
POST_Z = W;
POST_SIZE = 4;
POST_X0 = E + 2;
POLE_HOLE_DEPTH = 3;

// Finger stops behind each roller (as in v27): sloped front face reaching the wall top this far
// in front of the lock slot, its angle off vertical, and the round at its foot. The pinky's
// stands on a floor in the frame instead.
STOP_SETBACK = [5, 5, 1.34, 5];
STOP_ANGLE = [45, 35, 35, 35];
STOP_FOOT_R = [0, 3, 5, 3];
STOP_SIDE_R = 5; // fillet between the stop and the wall plate beside it
GAP_EDGE_R = 3; // plate bottom edge beside the open gap between seat and stop
PINKY_FLOOR_Z = 5;

// Anchor (as in v27): a bar rising at 45 degrees from the crossbar that ends in a tube; the cord
// runs along the tube bore. Its ends are 45 degree planes in plan through ANCHOR_X0 / ANCHOR_X1
// at the tube top.
ANCHOR_Y = LOCK_Y + 23.824;
ANCHOR_Z = WH + 5;
ANCHOR_R = 12.021;
ANCHOR_BORE_R = 5.242;
ANCHOR_X0 = E + WIDTH[P] + 2.255;
ANCHOR_X1 = roller_x(I) + WIDTH[I] / 2 - 2.185;
FRAME_TOP = ANCHOR_Y - ANCHOR_Z + ANCHOR_R * sqrt(2); // where the bar's underside meets the bed
CORD_EXIT_R = 3;

for (f = [R:I])
  assert(seat_end(f) < LOCK_Y - STOP_SETBACK[f] - WH * tan(STOP_ANGLE[f]),
         str(FINGERS[f], " seat (Y ", seat_end(f), ") runs into its finger stop"));

// ---------------------------------------------------------------------------------------------
// Rollers, pins, post

// Half profile (along the axis, radius) of roller f, w long: a circle of ROLLER_ARC_R through
// both ends at the roller radius, ends rounded by r.
module roller_half_profile(f, w, r) {
  a = ROLLER_ARC_R[f];
  rr = DIAMETER[f] / 2;
  center = [w / 2, rr + sqrt(a * a - w * w / 4)];
  intersection() {
    translate([-1, 0]) square([w + 2, rr + 1]);
    round2d(r) difference() {
      translate([0, -rr - 1]) square([w, 2 * rr + 2]);
      for (s = [1, -1]) translate([center[0], s * center[1]]) circle(a);
    }
  }
}

module roller(f) {
  w = WIDTH[f] - 2 * roller_side_clearance;
  difference() {
    about_x_axis(roller_x(f) + roller_side_clearance, axis_y(f), axis_z(f)) roller_half_profile(f, w, ROLLER_END_R);
    translate([roller_x(f) - 1, axis_y(f), axis_z(f)]) rotate([0, 90, 0]) cylinder(d = roller_bore_diameter, h = WIDTH[f] + 2);
  }
}

// Space cut under roller f: the roller scaled up by CRADLE_SCALE about its pinky-side end, at
// each tool offset; it reaches eps past both walls so its ends never coincide with their faces.
module cradle(f) {
  w = WIDTH[f] - 2 * roller_side_clearance;
  intersection() {
    for (o = CRADLE_TOOL_OFFSETS[f])
      about_x_axis(roller_x(f) + o, axis_y(f), axis_z(f)) scale(CRADLE_SCALE) roller_half_profile(f, w, ROLLER_END_R);
    translate([roller_x(f) - eps, -1, -1]) cube([WIDTH[f] + 2 * eps, 200, 200]);
  }
}

function pin_span(f) = [roller_x(f) - POLE_HOLE_DEPTH, roller_x(f) + WIDTH[f] + POLE_HOLE_DEPTH];
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

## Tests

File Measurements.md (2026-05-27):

## Left

| Finger | Full finger length | PIP-to-DIP | DIP-to-tip |
|---|---|---|---|
| Index | 73 mm | 23 mm | 25 mm |
| Middle | 78 mm | 28 mm | 25 mm |
| Ring | 70 mm | 25 mm | 27 mm |
| Pinky | 60 mm | 18 mm | 24 mm |

### Left (Computed)

| Finger | Vertical offset vs pinky | Horizontal offset vs pinky | Prometheus roof height |
|---|---:|---:|---:|
| Index | 13 mm | 5 mm | 16.24 mm |
| Middle | 18 mm | 10 mm | 14.43 mm |
| Ring | 10 mm | 7 mm | 15.59 mm |
| Pinky | 0 mm | 0 mm | 16.80 mm |

## Right

| Finger | Full finger length | PIP-to-DIP | DIP-to-tip |
|---|---|---|---|
| Index | 71 mm | 22 mm | 24 mm |
| Middle | 80 mm | 27 mm | 25 mm |
| Ring | 72 mm | 25 mm | 26 mm |
| Pinky | 60 mm | 18 mm | 24 mm |

### Right (Computed)

| Finger | Vertical offset vs pinky | Horizontal offset vs pinky | Prometheus roof height |
|---|---:|---:|---:|
| Index | 11 mm | 4 mm | 15.59 mm |
| Middle | 20 mm | 9 mm | 14.43 mm |
| Ring | 12 mm | 7 mm | 15.01 mm |
| Pinky | 0 mm | 0 mm | 16.80 mm |

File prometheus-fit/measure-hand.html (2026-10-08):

Choose, drop, or paste a hand photo

### 1. Photo

Palm up, fingers straight, ruler at palm height beside the fingers, camera parallel to the table. Scroll to zoom, drag to pan, drag a point to move it, click a step to place it again.

### 2. Points

Click the four circled points on every finger. The segments and how far each base crease sits along the hand place the roller (Height, Depth); DIP → tip sets the blocker (To_Blocker).

Distance between the two ruler marks (mm)

Pick two ruler marks far apart that span the fingers (e.g. 0 and 10 cm), not the palm: camera tilt changes the scale across the photo. If a joint has a double crease, click midway between the creases.

### 3. Results (mm)

Copy

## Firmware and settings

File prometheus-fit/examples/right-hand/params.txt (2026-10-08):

# Prometheus parameters (mm), right hand, from measure-hand.html on PXL_20261008_143506195.jpg, ruler 100 mm, 12.6 px/mm
# Index: base-PIP 21.8, PIP-DIP 21.7, DIP-tip 22.2, base offset 16.5
# Middle: base-PIP 25.1, PIP-DIP 25.9, DIP-tip 21.5, base offset 19.1
# Ring: base-PIP 20.8, PIP-DIP 25.6, DIP-tip 22.7, base offset 14.7
# Pinky: base-PIP 16.5, PIP-DIP 17.9, DIP-tip 20.5, base offset 0.0
# points {"ruler0":[926,1330],"ruler1":[926,2594],"I_base":[1949,2258],"I_pip":[1976,1984],"I_dip":[1998,1711],"I_tip":[2003,1430],"M_base":[1629,2244],"M_pip":[1612,1927],"M_dip":[1587,1601],"M_tip":[1575,1330],"R_base":[1387,2314],"R_pip":[1339,2056],"R_dip":[1268,1740],"R_tip":[1217,1458],"P_base":[1120,2516],"P_pip":[1084,2310],"P_dip":[1033,2089],"P_tip":[977,1836]}
Base_I_Height = 23.3
Base_I_Depth = 4.7
Base_I_To_Blocker = 14.4
# Measured M_Height 31.9 and R_Height 22.6 are spread by 2.2 mm each: the middle wall sketch
# needs the ring and middle pole rails separate (generate.check_rails).
Base_M_Height = 34.1
Base_M_Depth = 7.4
Base_M_To_Blocker = 12.4
Base_R_Height = 20.4
Base_R_Depth = 8.3
Base_R_To_Blocker = 13.1
Base_P_Height = 0.0
Base_P_Depth = 0.0
Base_P_To_Blocker = 14.4

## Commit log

2026-05-27 feat: Add initial openscad versions
    [OpenGrips_Prometheus_V42_from_step.scad, OpenGrips_Sisyphus_V25_from_step.scad, common.scad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]
2026-05-27 feat: add browser STL customizer
2026-05-27 feat: remove old files
    [OpenGrips_Prometheus.FCStd, OpenGrips_Prometheus_V42_from_step.scad, OpenGrips_Sisyphus.FCStd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]
2026-10-08 feat: add Prometheus hand fitting tools
    prometheus-fit/ measures a hand from a photo (measure-hand.html) and
    generates fitted, print-ready STLs from the original parametric FreeCAD
    model (generate.py), with printed pins sized like the v43 pins. Includes
    a right-hand example with its Bambu Lab A1 project. The root README only
    links to it so the fork's files stay untouched.
    [params.txt, prometheus_right_A1.3mf, prometheus_right_end_wall.stl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]
2026-10-08 feat: add parametric OpenSCAD model of Prometheus v43
    openscad/prometheus.scad rebuilds every part of the fork's v43 STEP
    (frame, walls, end wall, rollers, printed pins, post and TPU guard)
    from the original FreeCAD VarSet parameters, so measure-hand.html
    output applies unchanged. Each part exports in its print pose, left
    or right hand.
    At v43's blocker positions (the defaults) and frame height, every part
    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
    [prometheus.scad]
2026-10-08 refactor: move shared OpenSCAD building blocks to common.scad
    Extrusion and rounding helpers, pins, post, lock slot and the bore exit
    round move out of prometheus.scad so the Sisyphus model can reuse them.
    Parts are now dispatched from a table, and a blocker reaching the
    crossbar fails with a message instead of breaking the frame.
    All parts still match the v43 STEP as before.
    [common.scad, prometheus.scad]
2026-10-08 fix: round OpenSCAD edges without coincident faces
    The rounded end of along_x_rounded now has a core the sharp part ends
    inside, so the two share no faces; thin parts rounded on both faces
    were coming out non-manifold. The bore exit round crosses the faces it
    rounds instead of touching them, which left slivers. Prometheus' anchor
    web joints are rounded as in v43; the round was being overwritten.
    [common.scad, prometheus.scad]
2026-10-08 feat: add parametric OpenSCAD model of Sisyphus v27
    openscad/sisyphus.scad rebuilds every part of the fork's Sisyphus v27
    STEP from the original Sisyphus VarSet parameters (heights, seat
    blockers, roller sizes, frame length), exported in print pose for
    either hand. Features the original model lacks (finger stops, anchor,
    guard outline) keep v27's dimensions.
    At the defaults every part matches the STEP within 0.7% volume and,
    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
    [sisyphus.scad]
2026-10-08 feat: add OpenSCAD export and STEP comparison scripts
    export.py writes every part of one hand, optionally from a params.txt
    as measure-hand.html produces it; check_step.py compares each part with
    the STEP solid it rebuilds and fails beyond 1% volume or 0.6 mm at p95.
2026-10-08 docs: document the OpenSCAD models
    openscad/README.md covers use, parameters, printing and how faithful
    the models are; the root and prometheus-fit READMEs link to it and
    AGENTS.md records the model facts and checks for future changes.
2026-10-08 feat: drop the TPU guard from the OpenSCAD models
    Every remaining part prints in one material; the cord through the
    anchor is the only non-printed item. The guard carried no load and the
    anchor's cord exits are already rounded, so the frame works without it.
    The frame's cord switch, which only shaped the guard, goes with it.
    [prometheus.scad, sisyphus.scad]
2026-10-08 feat: default the Prometheus model to the measured right hand
    Height, Depth and To_Blocker now default to the measure-hand.html
    values from PXL_20261008_143506195.jpg, recorded in the model with
    v43's values next to them. check_step.py passes v43's values
    explicitly, so the STEP comparison is unchanged.
    [prometheus.scad]
2026-10-10 feat: engrave crimpdeq.com on both sides of Prometheus
    [prometheus.scad]
2026-10-11 docs: add illustrated Prometheus assembly book
2026-10-12 fix: add a brim to the Prometheus finger walls
